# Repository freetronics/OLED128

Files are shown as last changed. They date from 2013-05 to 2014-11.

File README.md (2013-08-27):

Kicad Schematic and PCB layout files for the Freetronics OLED128 module. Based around the SSD1351 OLED controller chip.

OLED128 PCB Front
OLED128 PCB Back

OLED128 Displaying Stripchart FTOLED sample sketch

Designed by Angus Gratton and Marc Alexander.

Copyright (C) 2013 Freetronics Pty Ltd. Open Source Hardware, licensed under the TAPR Open Hardware License.

# Resources

[OLED128 Home Page](http://freetronics.com/oled128)

[OLED128 QuickStart Guide](http://freetronics.com/pages/oled128-quickstart-guide)

[FTOLED Arduino Library](https://github.com/freetronics/FTOLED)

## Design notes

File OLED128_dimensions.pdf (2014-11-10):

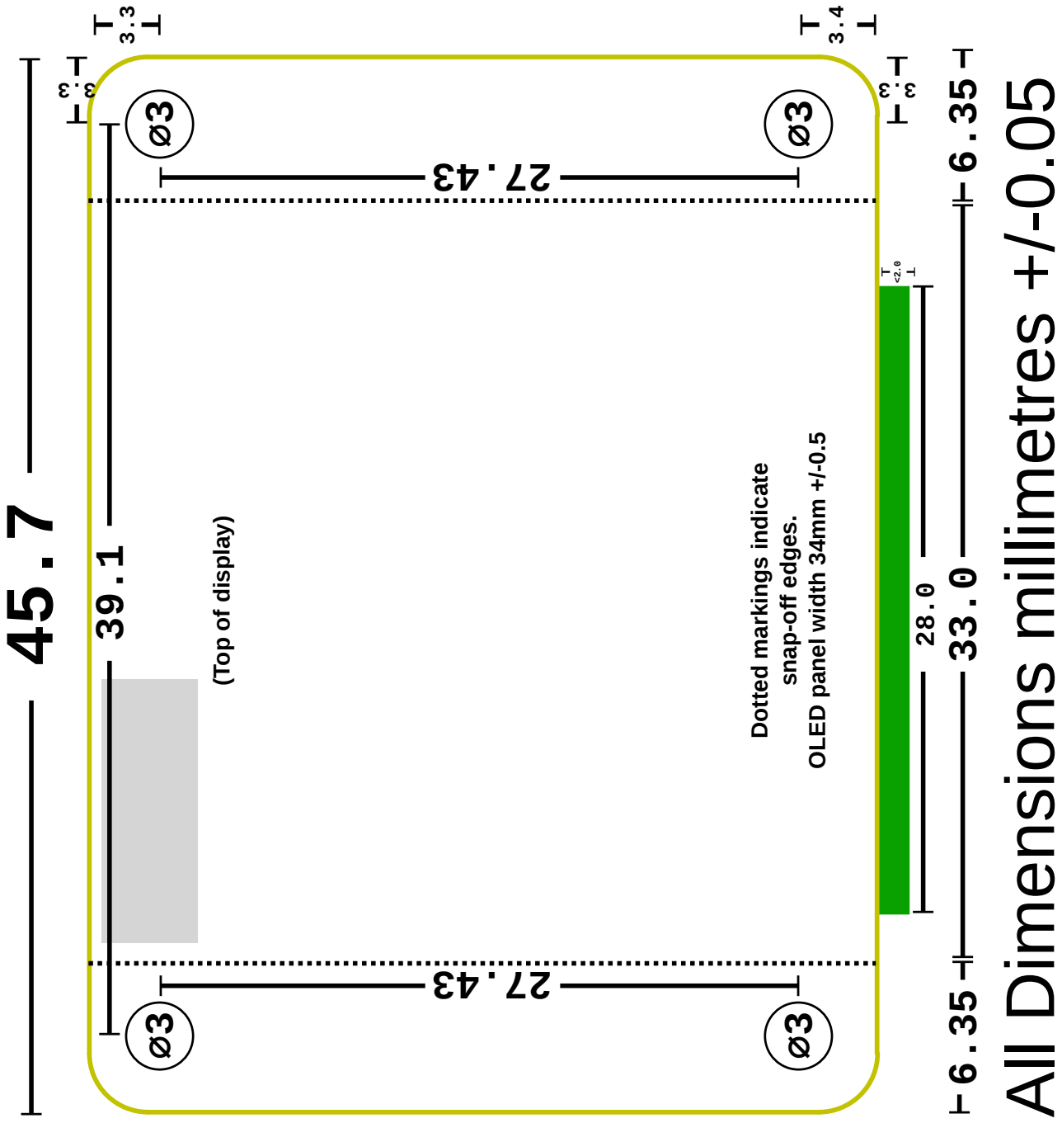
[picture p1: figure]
All Dimensions millimetres +/-0.05; (Top of display)

Freetronics OLED128 Dimensions v1.0

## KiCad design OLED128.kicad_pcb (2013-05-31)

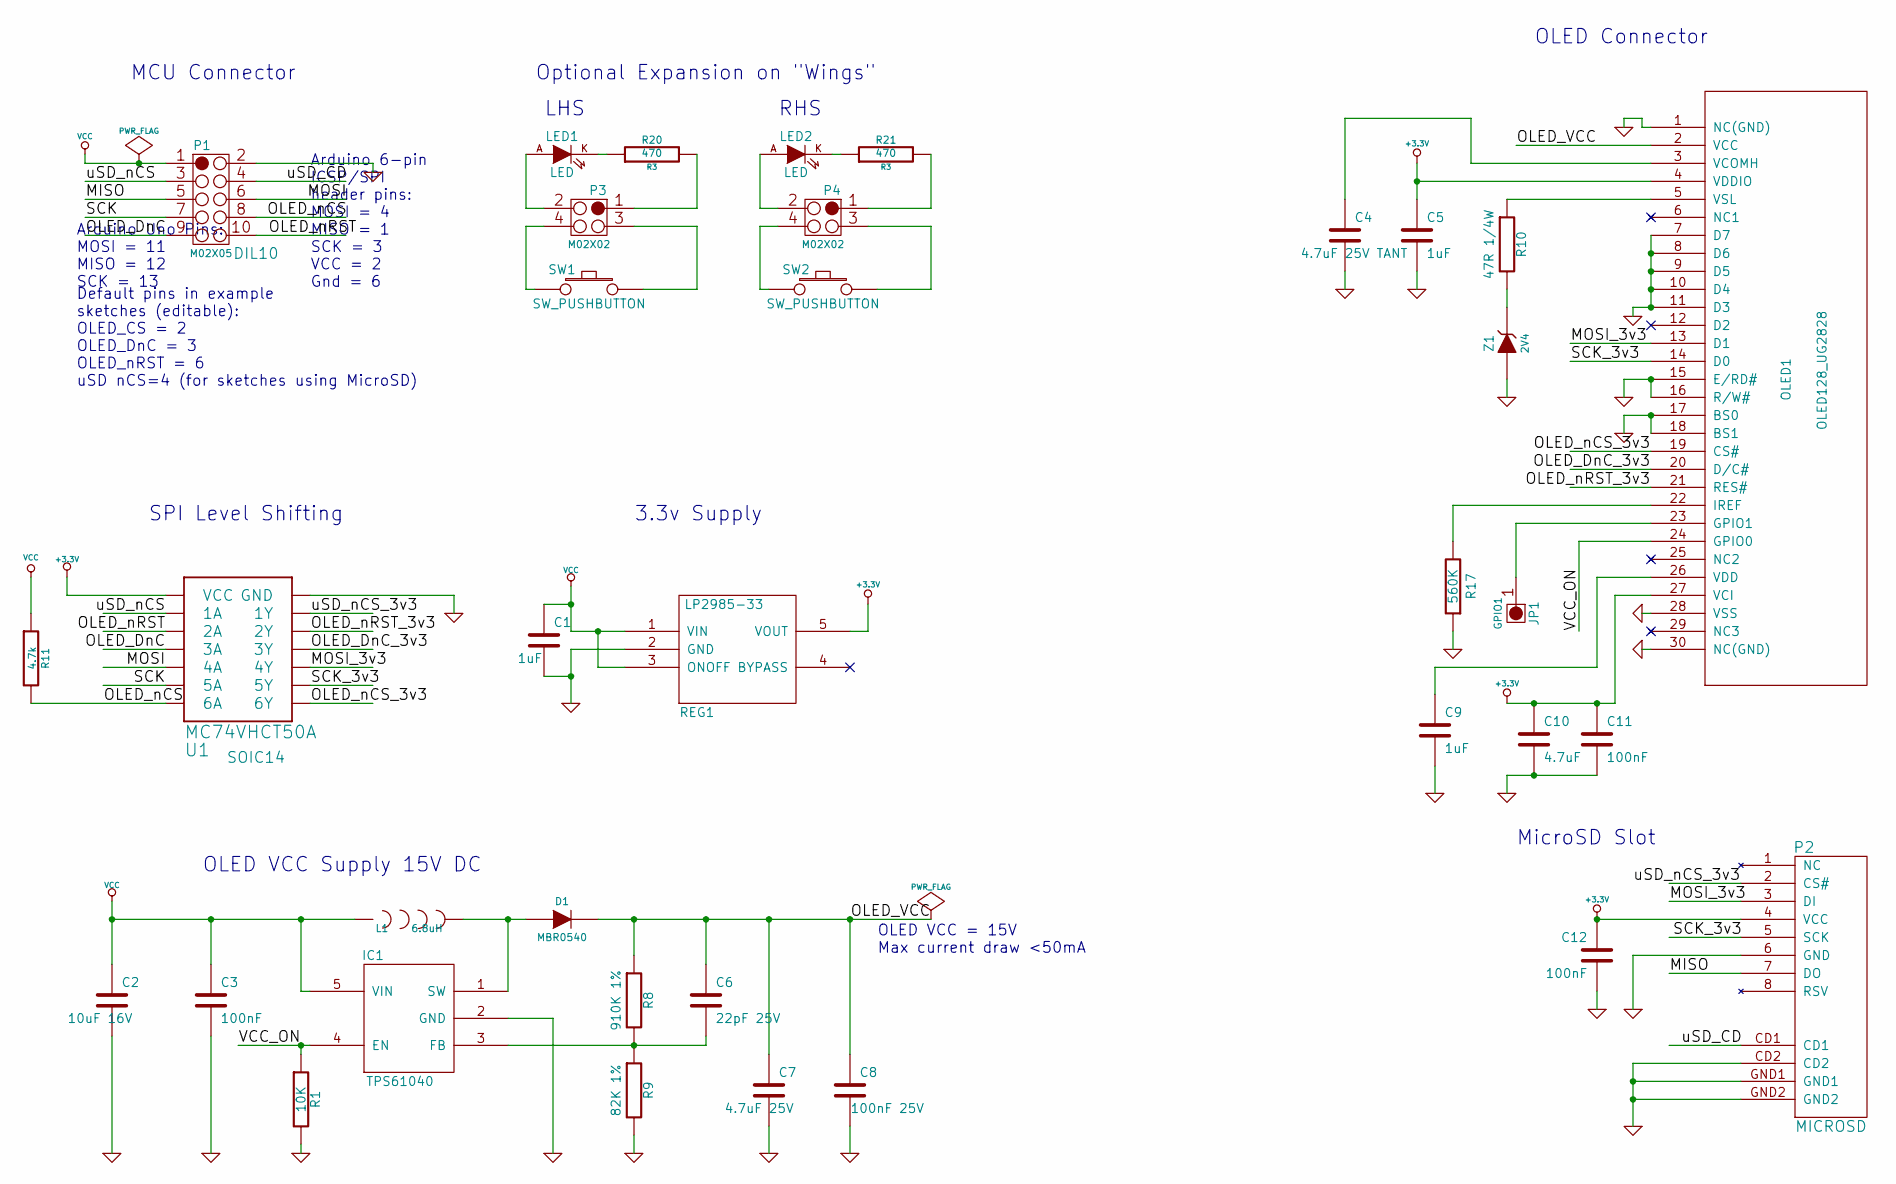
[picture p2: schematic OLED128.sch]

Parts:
C1, C5, C9: 1uF; 0603
C2: 10uF 16V; 0603
C3, C11, C12: 100nF; 0603
C4: 4.7uF 25V TANT; 1206
C6: 22pF 25V; 0603
C7: 4.7uF 25V; 0603
C8: 100nF 25V; 0603
C10: 4.7uF; 0603
D1: MBR0540; SOD-123
IC1: TPS61040; SOT23-5
JP1: GPIO1; 1X01
L1: 6.8uH; 1210
LED1, LED2: LED; LED3MM
OLED1: OLED128_UG2828; OLED-128X128-FPC-TOP
P1: M02X05; DIL10
P2: MICROSD; MICRO-SD-SOCKET-PP
P3, P4: M02X02; PIN_ARRAY_2X2
R1: 10K; 0603
R8: 910K 1%; 0603
R9: 82K 1%; 0603
R10: 47R 1/4W; 1206
R11: 4.7k
R17: 560K; 0603
R20, R21: 470; R3
REG1: LP2985-33; MODULE
SW1, SW2: SW_PUSHBUTTON; SW_TC0122
U1: MC74VHCT50A; SOIC14
Z1: 2V4; SOD-123

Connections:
+3.3V: C5.1, C10.1, C11.1, C12.1, OLED1.4 (VDDIO), OLED1.27 (VCI), P2.4 (VCC), REG1.5 (VOUT), U1.14 (VCC)
/MISO: P1.5, P2.7 (DO)
/MOSI: P1.6, U1.9 (4A)
/MOSI_3v3: OLED1.13 (D1), P2.3 (DI), U1.8 (4Y)
/OLED_DnC: P1.9, U1.5 (3A)
/OLED_DnC_3v3: OLED1.20 (D/C#), U1.6 (3Y)
/OLED_VCC: C6.1, C7.1, C8.1, D1.K, OLED1.2 (VCC), R8.1
/OLED_nCS: P1.8, R11.2, U1.13 (6A)
/OLED_nCS_3v3: OLED1.19 (CS#), U1.12 (6Y)
/OLED_nRST: P1.10, U1.3 (2A)
/OLED_nRST_3v3: OLED1.21 (RES#), U1.4 (2Y)
/SCK: P1.7, U1.11 (5A)
/SCK_3v3: OLED1.14 (D0), P2.5 (SCK), U1.10 (5Y)
/VCC_ON: IC1.4 (EN), OLED1.24 (GPIO0), R1.1
/uSD_CD: P1.4, P2.CD1
/uSD_nCS: P1.3, U1.1 (1A)
/uSD_nCS_3v3: P2.2 (CS#), U1.2 (1Y)
GND: C1.2, C2.2, C3.2, C4.2, C5.2, C7.2, C8.2, C9.2, C10.2, C11.2, C12.2, IC1.2 (GND), OLED1.1 (NC(GND)), OLED1.7 (D7), OLED1.8 (D6), OLED1.9 (D5), OLED1.10 (D4), OLED1.11 (D3), OLED1.15 (E/RD#), OLED1.16 (R/W#), OLED1.17 (BS0), OLED1.18 (BS1), OLED1.28 (VSS), OLED1.30 (NC(GND)), P1.2, P2.6 (GND), P2.CD2, P2.GND1, P2.GND2, R1.2, R9.2, R17.1, REG1.2 (GND), U1.7 (GND), Z1.A
unnamed: OLED1.22 (IREF), R17.2
unnamed: C4.1, OLED1.3 (VCOMH)
unnamed: D1.A, IC1.1 (SW), L1.2
unnamed: R10.2, Z1.K
unnamed: C6.2, IC1.3 (FB), R8.2, R9.1
unnamed: C9.1, OLED1.26 (VDD)
unnamed: OLED1.5 (VSL), R10.1
unnamed: P3.1, R20.2
unnamed: P3.4, SW1.1
unnamed: P3.3, SW1.2
unnamed: P4.3, SW2.2
unnamed: LED2.A, P4.2
unnamed: JP1.1, OLED1.23 (GPIO1)
unnamed: LED1.K, R20.1
unnamed: LED2.K, R21.1
unnamed: LED1.A, P3.2
unnamed: P4.4, SW2.1
unnamed: P4.1, R21.2
VCC: C1.1, C2.1, C3.1, IC1.5 (VIN), L1.1, P1.1, R11.1, REG1.1 (VIN), REG1.3 (ONOFF)

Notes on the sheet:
RHS
LHS
Optional Expansion on "Wings"
MicroSD Slot
SPI Level Shifting
MCU Connector
OLED Connector
OLED VCC Supply 15V DC
3.3v Supply
OLED VCC = 15V Max current draw <50mA
Arduino Uno Pins: MOSI = 11 MISO = 12 SCK = 13
Arduino 6-pin ICSP/SPI header pins: MOSI = 4 MISO = 1 SCK = 3 VCC = 2 Gnd = 6
Default pins in example sketches (editable): OLED_CS = 2 OLED_DnC = 3 OLED_nRST = 6 uSD nCS=4 (for sketches using MicroSD)

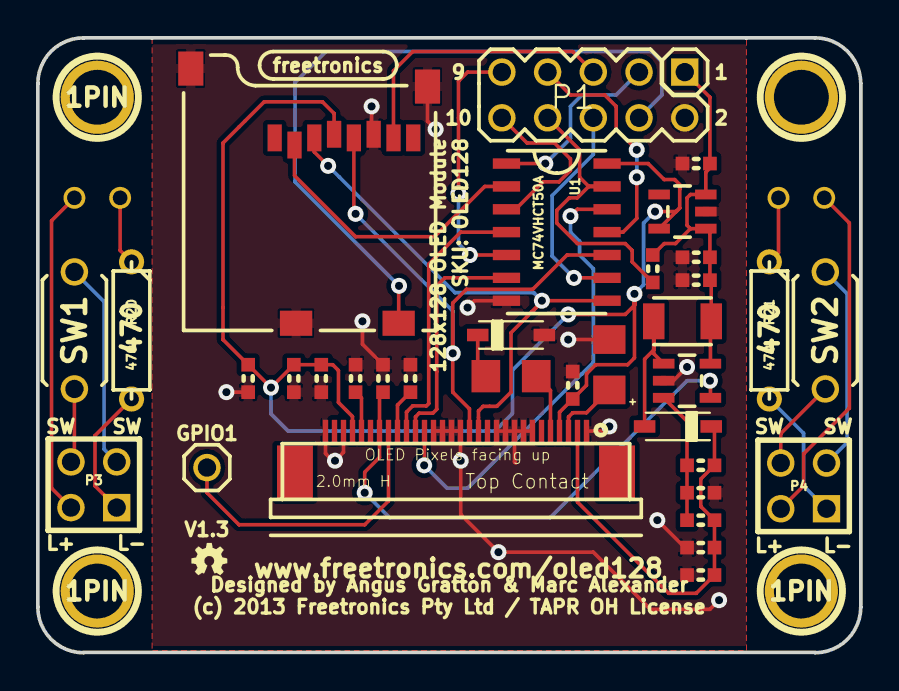
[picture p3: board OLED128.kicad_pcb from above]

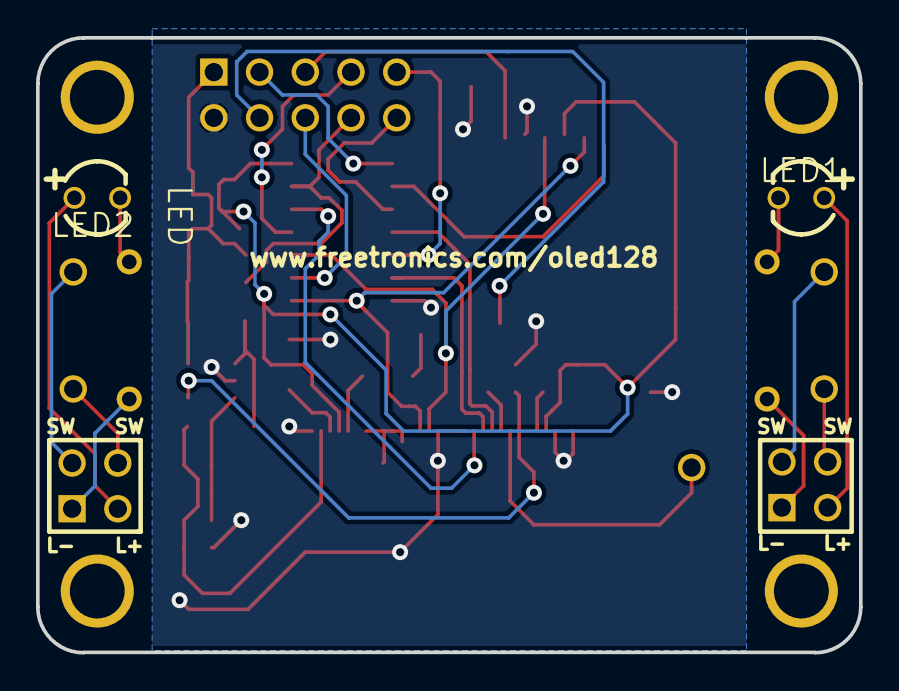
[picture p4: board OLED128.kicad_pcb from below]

Board: 2 copper layers, 45.7 x 34.2 mm, 41 parts (2 on the bottom side), 37 nets.

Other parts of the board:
1PIN, 1PIN#2, 1PIN#3, 1PIN#4: P***; 1pin
Ref**: Val**; LOGO_FREETRONICS_SMALL

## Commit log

2013-05-31 Initial commit, moved hardware components from FTOLED repo @ commit fe77584490bddff210091d671d63b1a6c4c6be1d
    [freetronics_oled128.brd, freetronics_oled128.sch]
2013-05-31 Rename board components, update pcb file to use new s-expression format
    [OLED128.kicad_pcb, OLED128.sch, freetronics_oled128.brd]
2013-08-27 Add README, LICENSE
    [OLED128.sch]

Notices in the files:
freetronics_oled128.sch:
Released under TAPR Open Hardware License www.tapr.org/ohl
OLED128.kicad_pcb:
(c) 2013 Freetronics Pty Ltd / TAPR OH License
